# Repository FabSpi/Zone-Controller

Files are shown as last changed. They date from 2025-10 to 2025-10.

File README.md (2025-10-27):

# General-Purpose-ECU
This General Purpose ECU was developed as the core project of my Bachelor's thesis. The objective was to design an ECU versatile enough to function as a **Zone Controller**, 
an **Intra-Zone ECU**, or a **Peripheral Device**. This development establishes a foundational component for test setups dedicated to researching future automotive architectures.

## Concept
The use cases of the board can be seen in the picture below.



In order to implement this versatility, several bus interfaces were implemented on the board.



## Top Side
Zonencontroller_top

## Bottom Side
Zonencontroller_bottom

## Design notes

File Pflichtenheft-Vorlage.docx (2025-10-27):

# Fabian Spitz

Pflichtenheft Zonencontroller für die mobile Plattform Magni Silver

Projektbezeichnung | Zonencontroller für die mobile Plattform Magni Silver
Projektleiter | Fabian Spitz
Erstellt am | 24.10.24
Letzte Änderung am | 27.10.24
Status | In Bearbeitung
Aktuelle Version | 1.4

Änderungsverlauf

Nr. | Datum | Version | Geänderte Kapitel | Art der Änderung | Autor | Status
1 | 24.10.2024 | 1.0 | Alle | Erstellung | Fabian Spitz | -
2 | 24.10.2024 | 1.1 | Funktionale Anforderungen | Geforderten Footprint von LQFP auf HDQFP geändert | Fabian Spitz
3 | 27.10.2024 | 1.2 | Funktionale Anforderungen | Geforderte maximale Eingangsspannung von 48V auf 40V gesenkt, um FS26 benutzen zu können | Fabian Spitz
4 | 29.10.2024 | 1.3 | Funktionale Anforderungen | Segger 6-pin Stecker auf 10-pin Stecker geändert | Fabian Spitz
5 | 29.10.2024 | 1.4 | Funktionale Anforderungen | CAN Transceiver von TJA1153 auf TJA1443 | Fabian Spitz

# 1 Einleitung

Das vorliegende Pflichtenheft enthält die an das zu entwickelnde Produkt gestellten funktionalen sowie nicht-funktionalen Anforderungen. Mit den Anforderungen werden die Rahmenbedingungen für die Entwicklung festgelegt, die vom Bearbeiter im Pflichtenheft detailliert ausgestaltet werden.

# 2 Allgemeines

## 2.1 Ziel und Zweck des Dokuments

Dieses Pflichtenheft beschreibt die funktionalen und nicht funktionalen Anforderungen an den Zonencontroller für die mobile Plattform Magni Silver. Die in ihm enthaltenen Anforderungen an das Projekt sollen gemeinsam von Bearbeiter (Fabian Spitz) und Betreuer (Maximilian Beck und Vitus Lüntzel) besprochen und abgesegnet werden, Sie dienen als Grundlage für die spätere Verifikation des Zonencontrollers.

## 2.2 Projektbezug

Das vorliegende Projekt ist ein unabhängiges Projekt im Rahmen einer Bachelorarbeit am Institut für Informationsverarbeitung (ITIV) am Karlsruher Institut für Technologie.

## 2.3 Abkürzungen

- ECU – Electronic Control Unit
- ADC – Analog to Digital converter
- GPIO – General-Purpose Input/Output
- CAN-FD - Controller Area Network Flexible Data-Rate
- CAN - Controller Area Network
- CAN-H/L- Controller Area Network High/Low
- EMI - Electromagnetic Interference
- JTAG - Joint Test Action Group
- uC – Microcontroller
- CAN PHY - Controller Area Network Physical Layer
- ETH PHY – Ethernet Physical Layer
- SPI – Serial Pheriperal Interface
- I2C - Inter-Integrated Circuit

## 2.4 Teams und Schnittstellen

Rolle(n) | Name | E-Mail
Bearbeiter | Fabian Spitz | ufgvw@student.kit.edu
Betreuer | Vitus Lüntzel | vitus.luentzel@kit.edu
Betreuer | Maximilian Beck | maximilian.beck@kit.edu

# 3 Konzept

## 3.1 Ziel(e) und Nutzen des Anwenders

Durch den neu entwickelten Zonencontroller soll die Grundlage für eine neue Architektur für die Plattform Magni Silver geschaffen werden, um in Zukunft in der Lage zu sein eine zonenbasierte E/E-Architektur umsetzten zu können. Mit dem Zonencontroller wird es außerdem möglich sein, eine zonenbasierte Bordnetzarchitektur auch in anderen Projekten umzusetzen.

# 4 Funktionale Anforderungen

## 4.1 Case

- The GP_ECU must have the following dimensions: 100mm x 120mm x 40mm (BxTxH).

With the Molex connector & the Mounting Brackets in place in place the ECU shall have the following maximum dimesions: 130mm x 140mm x 40mm (BxTxH).

- The GP_ECU must be enclosed in a Case.
- A Molex (Nr. 5007620481) shall be used to connect the ecu with the external wiring harness.

## 4.2 Operation Environment

- THE GP_ECU shall be certified according to IP standart. It should withstand IP 55.
- The GP_ECU shall be operable in a 5-40V Environment.
- The GP_ECU shall be operable in a Environment from -40 to +105 Degrees Celsius.

## 4.3 GPIO

- The GP_ECU shall have inputs which are readable in a digital state. Ideally the pins connected to interrupts are used preferably.
- The GP_ECU shall have outputs which are wirtable in a digital state.
- The GP_ECU shall have at least 2 ADC Channels with at least 12bit
- External Access to at least 5 Inputs , 5 Outputs , and 2 ADCs shall be provided by the Molex Connector (External Connector)

## 4.4 CAN

- The Can Interface should be able to understand CAN-FD Messages as specified in the ISO 11898-1.
- There shall be 2 Interfaces available from the external connector. CAN A, CAN B
- The CAN interface shall alow connection speeds up to 1000k with a stable transmission rate at 500k.
- The following adressing formats shall be supported: Extended; Mixed11; Mixed29; Normal Fixed; Standard
- The CAN Interface shall support Long First Frames
- External Access to at least one CAN-H/L pair shall be provided by the Molex Connector (External Connector)

## 4.5 Ethernet

- The GP_ECU shall have one single ethernet interface
- External Access to the ethernet twisted pair line shall be provided by the Molex Connector (External Connector)
- The GP_ECU Shall support 100BASE-T1 Ethernet Interface with reduced EMI at 10 – 100 Mbps speeds

## 4.6 JTAG

- There should be a 10 pin JTAG connector on the PCB
- The Seeger 10 pin JTAG Adapter shall be used: https://www.segger.com/products/debug-probes/j-link/accessories/adapters/6-pin-needle-adapter/. The apropriate footprints shall be used.

## 4.7 uC

- The uC shall be selected from the ST32K3XX Series
- HDQFP – Enclosure shall be selected

## 4.8 CAN PHY

- As secure Can Reciver the NXP TJA1443 shall be used. To be checkd if it can support CAN-XL

## 4.9 ETH PHY

- As Automotive Ethernet PHY the TJA1103 shall be used.

## 4.10 SPI

- SPI can be optionally routed to the Molex connector if there are pins left

## 4.11 I2C

- I2C can be optionally routed to the Molex connector if there are pins left

# 4 Rahmenbedingungen

## 5.1 Zeitplan

Ziel des Projekts ist es, bis Ende KW 46 einen Schaltplan zu erstellen, sodass im Anschluss daran das PCB designt werden kann, welches bis Ende KW 49 fertiggestellt werden soll. Aufgrund von Fertigungszeiten der Platine uns Lieferzeiten der Bauteile und der Weihnachtsferien ist eine Inbetriebnahme des Zonencontrollers in KW2 2025 geplant, welche bis Ende KW2 abgeschlossen werden soll.

## 5.2 Technische Anforderungen

Für das Design des Zonencontrollers wird die Software KiCAD benötigt. Für die spätere Inbetriebnahme wird ein Netzteil sowie Equipment zum Flashen des Mikrocontrollers benötigt

## 5.3 Problemanalyse

## 5.4 Qualität

# 5 Anhang

Alle weiteren Dokumente oder Zahlen und Fakten, die als Hintergrund zu dem Projekt dienen.

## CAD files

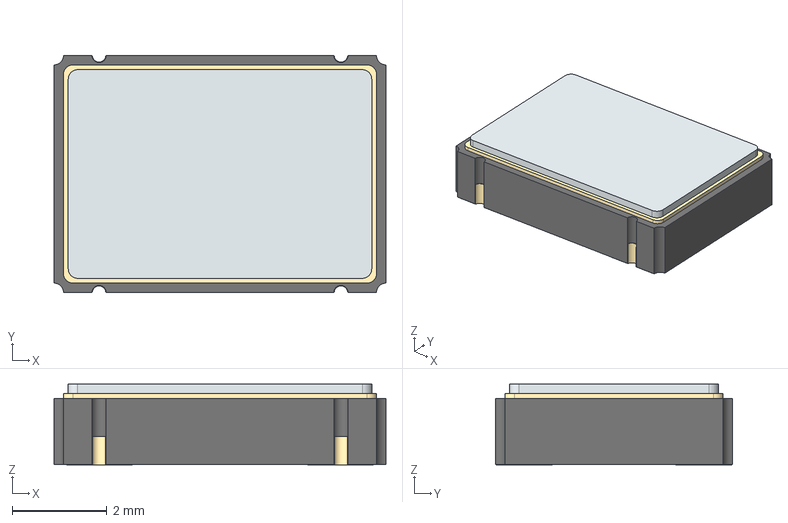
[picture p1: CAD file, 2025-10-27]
KiCAD_libs/ECS-3953M-500-BN-TR.step
7.00 x 5.00 x 1.70 mm
terminal

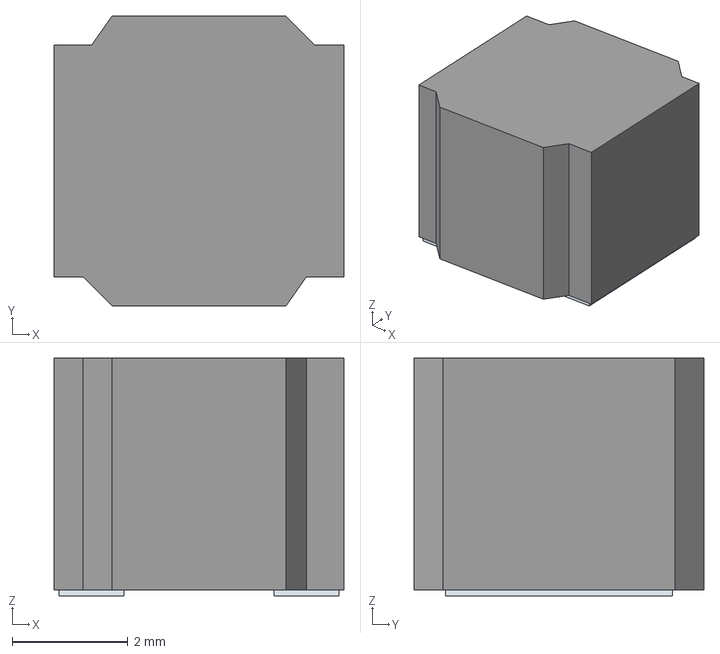
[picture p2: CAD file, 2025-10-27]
KiCAD_libs/IFSC2020DZER1R0N01.step
5.00 x 5.00 x 4.10 mm
Pins

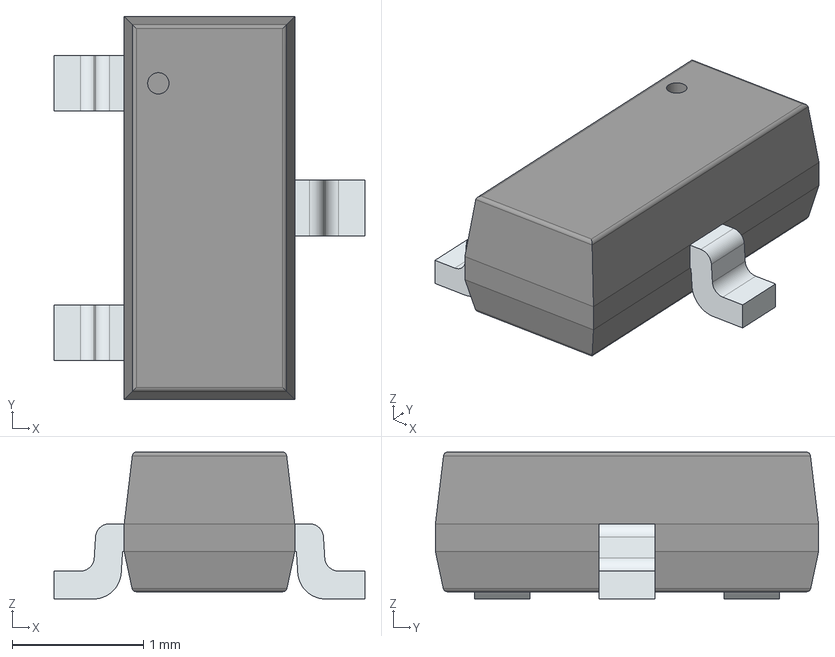
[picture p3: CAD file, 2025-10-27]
KiCAD_libs/SI2302ADS-T1-E3.step
2.37 x 2.92 x 1.12 mm
PinsArrayL
FilletPinR

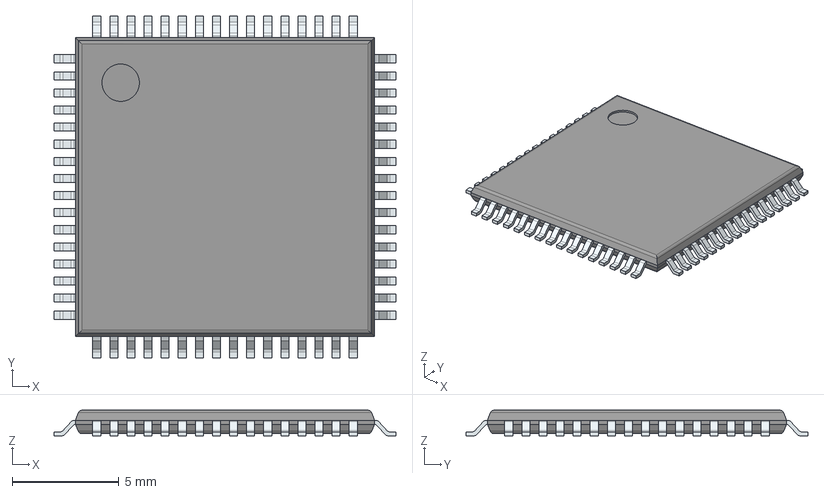
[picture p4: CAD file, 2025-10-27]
KiCAD_libs/ATMEGA649A-AU.step
16.0 x 16.0 x 1.20 mm
PinsArrayLR
PinsArrayTB

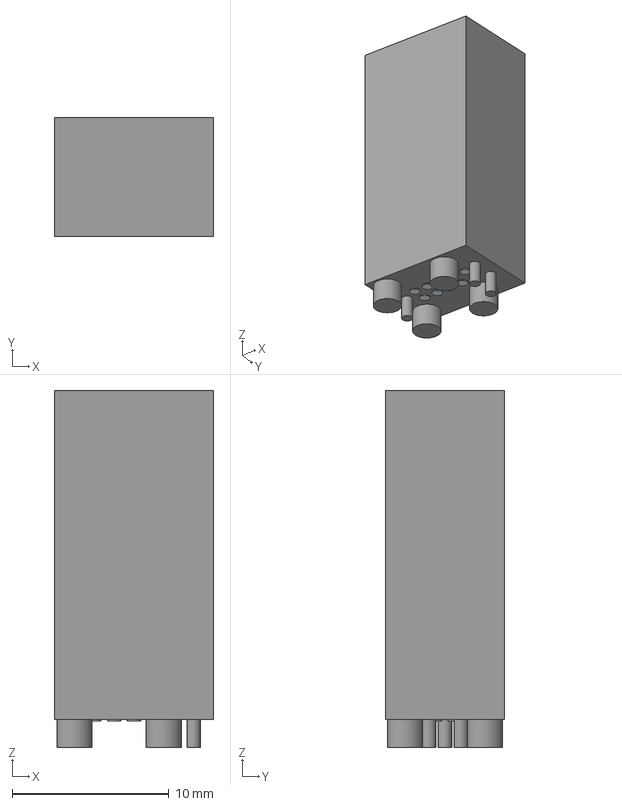
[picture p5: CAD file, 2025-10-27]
KiCAD_libs/8.06.04.step
10.2 x 7.62 x 22.8 mm
Pins
Lugs x 7

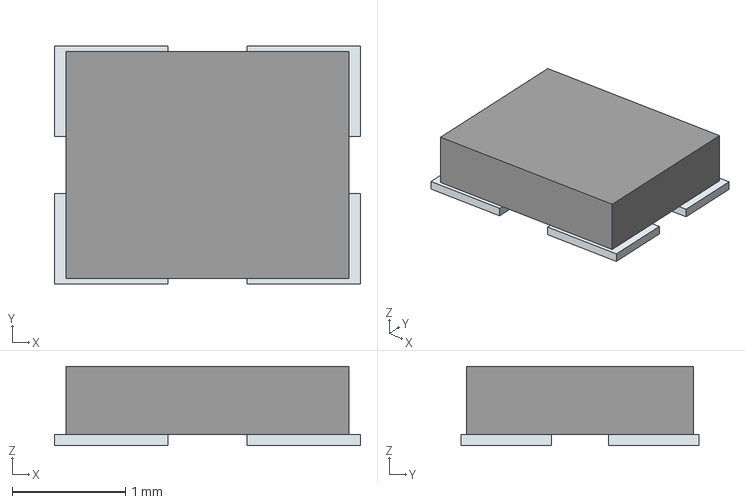
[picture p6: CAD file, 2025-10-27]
KiCAD_libs/ECS-160-10-36Q-ES-TR.step
2.70 x 2.10 x 0.7 mm
Pins

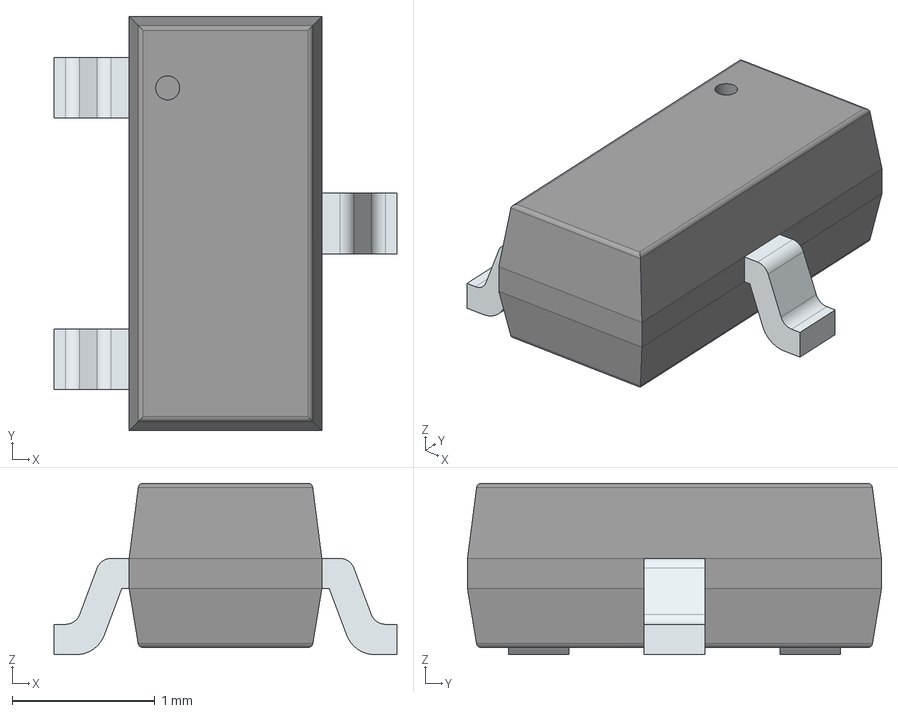
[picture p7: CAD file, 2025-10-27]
KiCAD_libs/BC846BT116.step
2.40 x 2.90 x 1.20 mm
PinsArrayL
FilletPinR

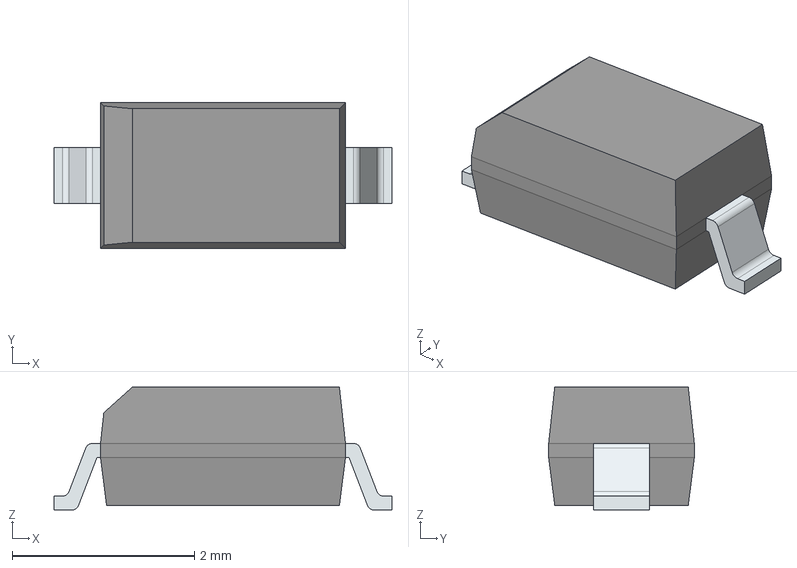
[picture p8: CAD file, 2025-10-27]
KiCAD_libs/MMSZ8V2T1G.step
3.71 x 1.60 x 1.35 mm
FilletPinL
FilletPinR

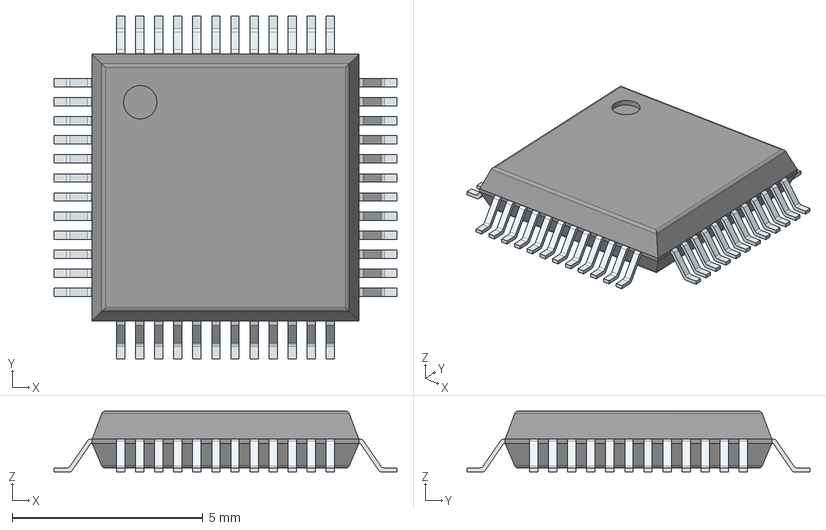
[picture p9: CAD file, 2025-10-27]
KiCAD_libs/STM32F103CBT6TR.step
9.00 x 9.00 x 1.60 mm
PinsArrayLR
PinsArrayTB

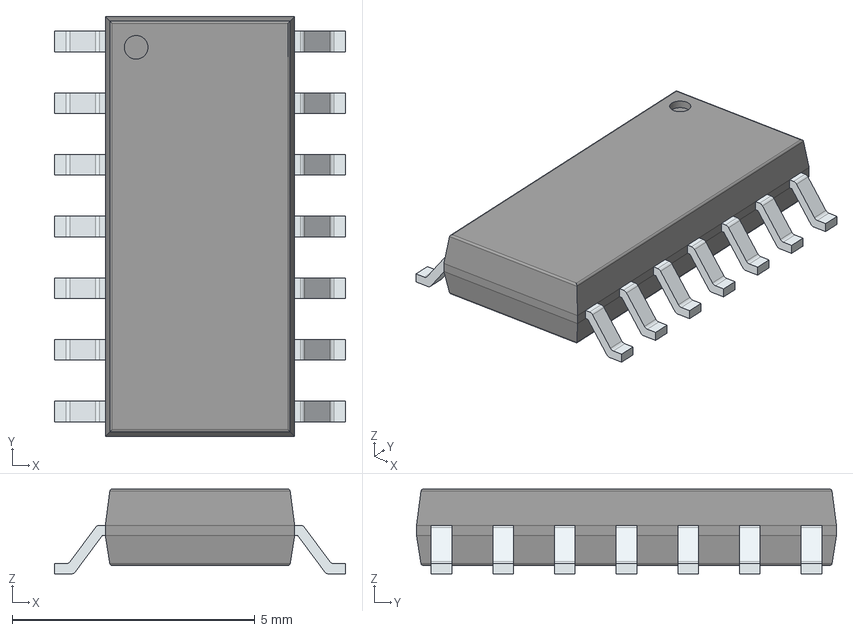
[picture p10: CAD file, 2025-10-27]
KiCAD_libs/TJA1022T.step
6.00 x 8.65 x 1.75 mm
PinsArrayLR

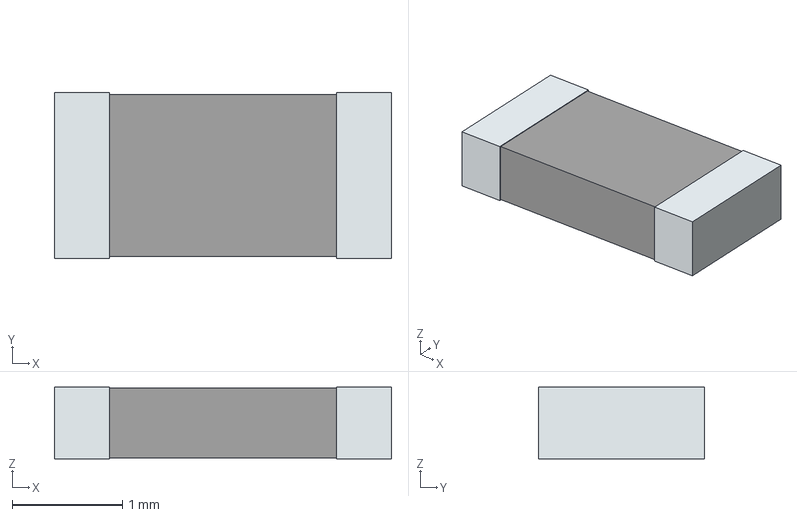
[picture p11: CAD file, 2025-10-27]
KiCAD_libs/TFPT1206L1002FM.step
3.05 x 1.50 x 0.65 mm
term1
term2

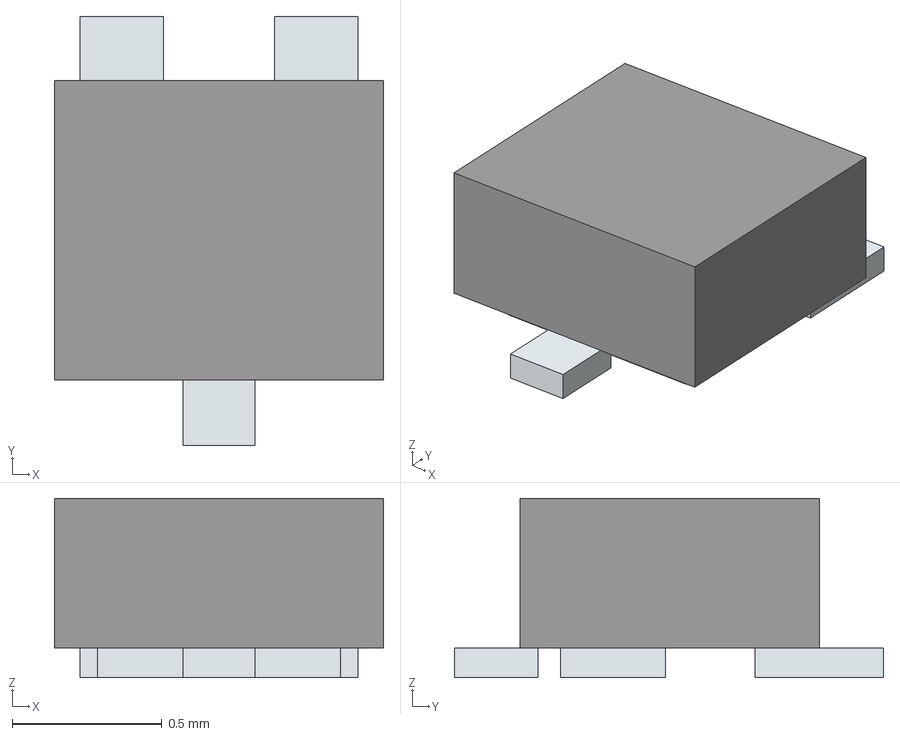
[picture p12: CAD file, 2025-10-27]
KiCAD_libs/PESD2CANFD36LQB-QZ.step
1.10 x 1.44 x 0.6 mm
Pins

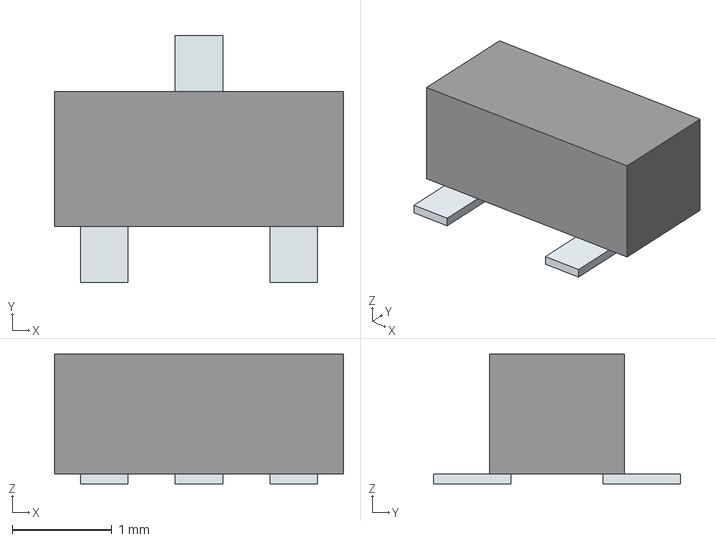
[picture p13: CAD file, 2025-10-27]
KiCAD_libs/BC857BT116.step
2.90 x 2.48 x 1.30 mm
Pins

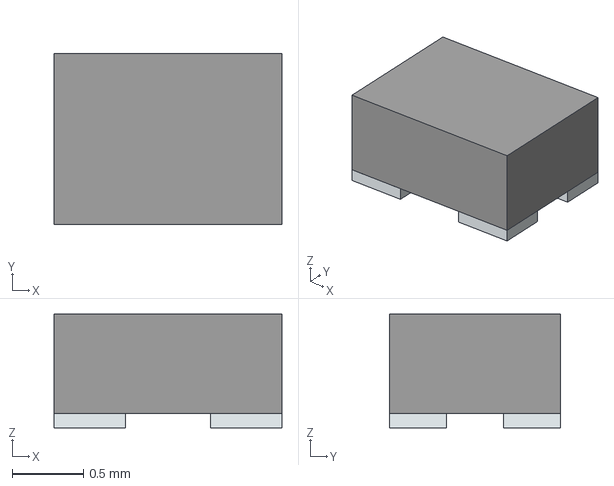
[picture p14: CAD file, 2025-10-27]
KiCAD_libs/ECS-1612MV-271.2-CN-TR.step
1.60 x 1.20 x 0.8 mm
Pins

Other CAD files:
KiCAD_libs/BC847BVN-7.step
KiCAD_libs/TJA1022TK_118.step
KiCAD_libs/MFS2633AMBA0AD.step
KiCAD_libs/TJA1101BHN_0Z.step
KiCAD_libs/0458003.DR.step
KiCAD_libs/74477110W.step
KiCAD_libs/8.06.04_J-LINK_NEEDLE_ADAPTER.step
KiCAD_libs/830033075.step
KiCAD_libs/830034122.step
KiCAD_libs/830108288709.step
KiCAD_libs/MPLC0730L4R7.step
KiCAD_libs/NE555DR.step

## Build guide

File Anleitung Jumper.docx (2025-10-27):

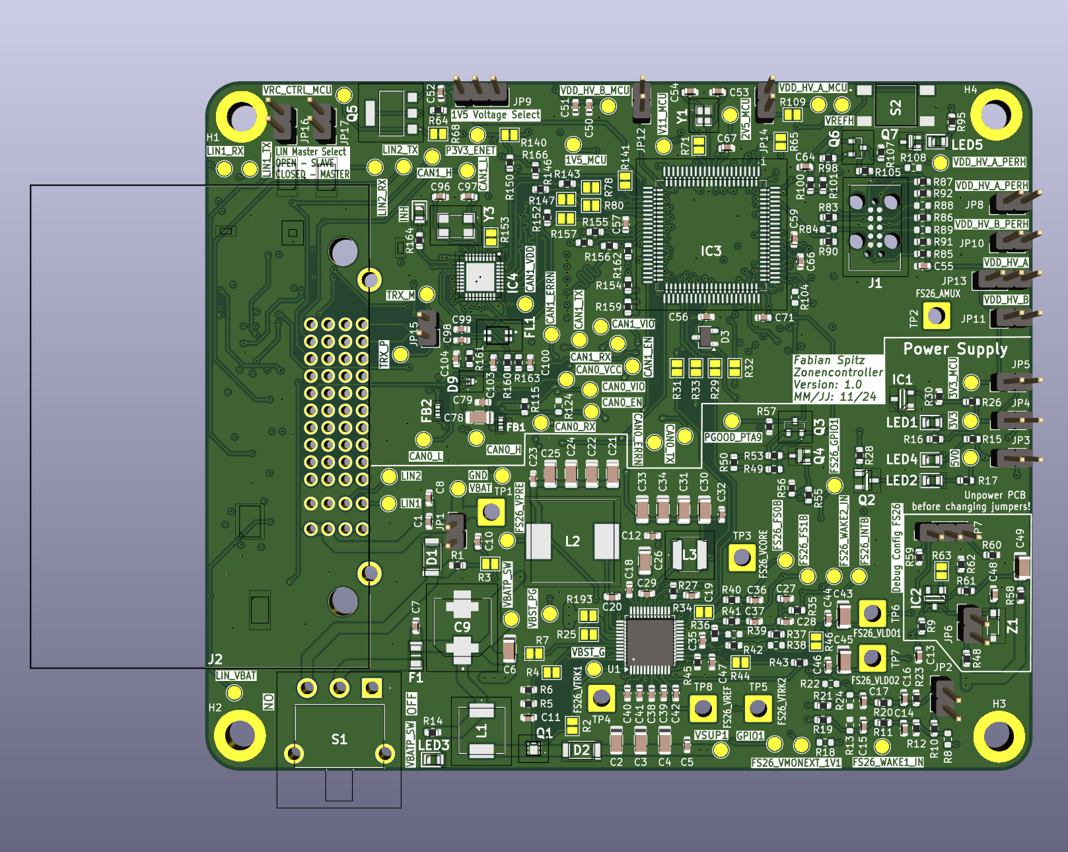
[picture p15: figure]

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
1 - Jumper, um Spannungseingang am Molexstecker mit S1 (Schalter an Seite von Zonencontroller) zu verbinden

2 - Jumper zum Verbinden der beiden WAKE-Pins am FS26

3/4 – Jumper zum Festlegen der Debug-Konfiguration für den FS26

Beide offen → Normal Mode

3 geschlossen → 4 links gesetzt → Flash Mode

- 4 rechts gesetzt → Debug Mode

5 LDO1 von FS25 mit 5V0-Versorgung auf der Platine verbinden

6 LDO2 von FS26 mit 3V3-Versorgung auf der Platine verbinden

7 Verbinden von 3V3 mit 3V3_MCU zur Versorgung des Mikrocontrollers

8 Verbinden von 3V3_MCU mit VDD_HV_B

9 Verbinden von 5V0 oder 3V3 mit VDD_HV_A (Jumper rechts: VDD_HV_A = 5V0, Jumper links: VDD_HV_A = 3V3)

10 Verbinden von VDD_HV_B und VDD_HV_B_PERH

11 Verbinden von VDD_HV_A und VDD_HV_A_PERH

12 Verbinden von VDD_HV_A und VDD_HV_A_MCU

13 Verbinden von VDD_HV_B und VDD_HV_B_MCU

14 1V5 Voltage-Selector für Mikrocontroller (Jumper links: 1V5 von FS26_VCORE, Jumper rechts: 1V5 von VDD_HV_B_MCU über externen Ballasttransisitor)

15/16 Jumper für Selektion, ob Zonencontroller LIN-Master oder LIN-Slave ist (beide offen: Slave, beide geschlossen: Master)

17 Jumper, um beide TRX-Leitungen von Ethernet zu verbinden

Inbetriebnahme Zonencontroller

1. Schalter S1 nach rechts stellen
2. Jumper 1 verbinden und Schalter S1 nach links stellen → Spannungen an LDO1, LDO2 und VCORE messen
3. Falls Spannungen passen, S1 nach rechts stellen
4. Jumper 5, 6, 7, 9, 12 schließen und S1 wieder nach links stellen
5. Jumper 14 links schließen
6. Schauen, ob Mikrocontroller flashbar ist
7. Falls ja, Jumper 8, 10, 11,13 schließen
8. Ethernet und CAN testen
9. Jumper 15/16 entsprechend einstellen und LIN testen
